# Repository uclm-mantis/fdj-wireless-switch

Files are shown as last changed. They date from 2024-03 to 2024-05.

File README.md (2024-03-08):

# FdJ Wireless Switch

Primera versión del conmutador inalámbrico para juguetes adaptados. Utiliza ESP Now! sin cifrado y sin filtrado de fuente.

## Configuración del emisor

En `emisor/main/main.cpp` editar la definición de pulsadores. El campo `.id` se utiliza para ligarlo a la salida con el mismo valor en el receptor.

```c
pulsador pulsadores[] = {
    {  .pin = 44, .id = 1 },
    {  .pin = 7,  .id = 2 },
    {  .pin = 8,  .id = 3 },
    {  .pin = 9,  .id = 4 },
};
```

En el mismo archivo, justo a continuación, editar la definición de `peer`. Solo debería editarse la MAC en `.peer_addr` y el canal WiFi en `.channel`.

```c
esp_now_peer_info_t peer = {
    .peer_addr = { 0x40, 0x4C, 0xCA, 0xF9, 0xE6, 0x34 },
    .channel = 0,
    .encrypt = false
};
```

## Configuración del receptor

En `receptor/main/main.cpp` editar la definición de las salidas. El campo `.id` debe coincidir con el correspondiente emisor. El campo `.pinModoPulsador` es una entrada digital para configurar modo pulsador (*press* activa, *release* desactiva) o modo conmutador (*press* conmuta el estado).

```c
salida salidas[] = {
    { .id = 1, .pin = 6,   .pinModoPulsador = 0 },
    { .id = 2, .pin = 7,   .pinModoPulsador = 1 },
    { .id = 3, .pin = 8,   .pinModoPulsador = 3 },
    { .id = 4, .pin = 10,  .pinModoPulsador = 4 },
};
```

# TODO

- Mecanismo para configurar peer.
- Deep sleep al menos en emisor.

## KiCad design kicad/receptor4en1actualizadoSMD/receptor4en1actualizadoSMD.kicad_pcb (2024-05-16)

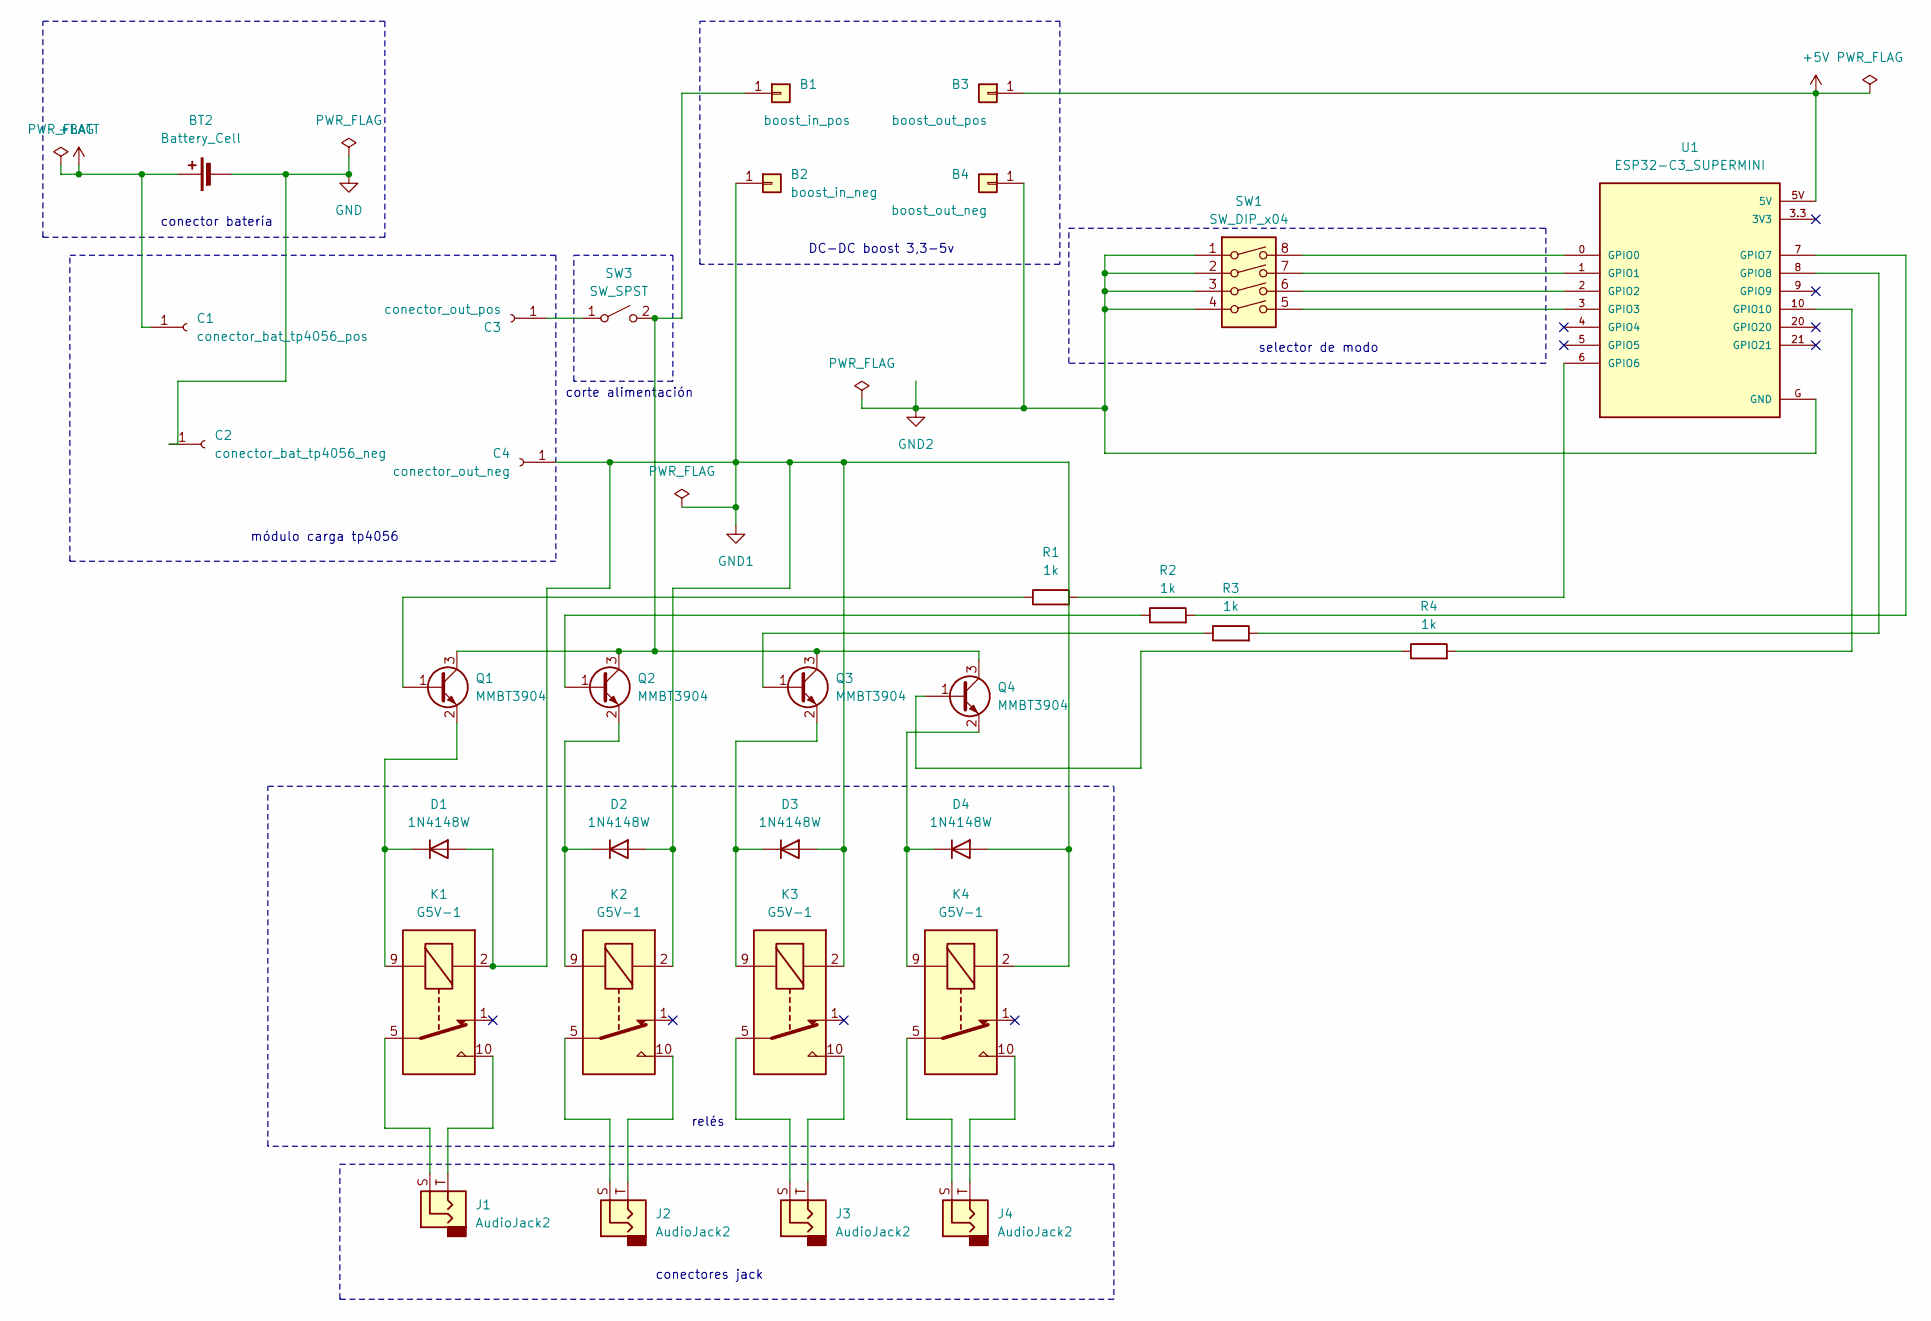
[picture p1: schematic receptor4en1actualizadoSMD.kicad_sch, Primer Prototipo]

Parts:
B1: boost_in_pos; PinHeader_1x01_P2.54mm_Vertical
B2: boost_in_neg; PinHeader_1x01_P2.54mm_Vertical
B3: boost_out_pos; PinHeader_1x01_P2.54mm_Vertical
B4: boost_out_neg; PinHeader_1x01_P2.54mm_Vertical
BT2: Battery_Cell; JST_PH_S2B-PH-K_1x02_P2.00mm_Horizontal
C1: conector_bat_tp4056_pos; PinHeader_1x01_P2.54mm_Vertical
C2: conector_bat_tp4056_neg; PinHeader_1x01_P2.54mm_Vertical
C3: conector_out_pos; PinHeader_1x01_P2.54mm_Vertical
C4: conector_out_neg; PinHeader_1x01_P2.54mm_Vertical
D1, D2, D3, D4: 1N4148W; D_SOD-123
J1, J2, J3, J4: AudioJack2; Jack_3.5mm_CUI_SJ1-3523N_Horizontal
K1, K2, K3, K4: G5V-1; Relay_SPDT_Omron_G5V-1
Q1, Q2, Q3, Q4: MMBT3904; SOT-23
R1, R2, R3, R4: 1k; R_0805_2012Metric_Pad1.20x1.40mm_HandSolder
SW1: SW_DIP_x04; DIP-8_W7.62mm_Socket
SW3: SW_SPST; JST_EH_S2B-EH_1x02_P2.50mm_Horizontal
U1: ESP32-C3_SUPERMINI; MODULE_ESP32-C3_SUPERMINI

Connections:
+5V: B3.1, U1.5V
+BATT: BT2.1 (+), C1.1
GND: BT2.2 (-), C2.1
GND1: B2.1, C4.1, D1.2 (A), D2.2 (A), D3.2 (A), D4.2 (A), K1.2, K2.2, K3.2, K4.2
GND2: B4.1, SW1.1, SW1.2, SW1.3, SW1.4, U1.G (GND)
unnamed: B1.1, Q1.3 (C), Q2.3 (C), Q3.3 (C), Q4.3 (C), SW3.2 (B)
unnamed: C3.1, SW3.1 (A)
unnamed: D1.1 (K), K1.9, Q1.2 (E)
unnamed: D2.1 (K), K2.9, Q2.2 (E)
unnamed: D3.1 (K), K3.9, Q3.2 (E)
unnamed: D4.1 (K), K4.9, Q4.2 (E)
unnamed: J1.S, K1.5, K1.6
unnamed: J1.T, K1.10
unnamed: J2.S, K2.5, K2.6
unnamed: J2.T, K2.10
unnamed: J3.S, K3.5, K3.6
unnamed: J3.T, K3.10
unnamed: J4.S, K4.5, K4.6
unnamed: J4.T, K4.10
unnamed: Q1.1 (B), R1.1
unnamed: Q2.1 (B), R2.1
unnamed: Q3.1 (B), R3.1
unnamed: Q4.1 (B), R4.1
unnamed: SW1.8, U1.0 (GPIO0)
unnamed: SW1.7, U1.1 (GPIO1)
unnamed: SW1.6, U1.2 (GPIO2)
unnamed: SW1.5, U1.3 (GPIO3)
unnamed: R1.2, U1.6 (GPIO6)
unnamed: R2.2, U1.7 (GPIO7)
unnamed: R3.2, U1.8 (GPIO8)
unnamed: R4.2, U1.10 (GPIO10)

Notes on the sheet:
conectores jack
selector de modo
relés
DC-DC boost 3,3-5v
corte alimentación
conector batería
módulo carga tp4056

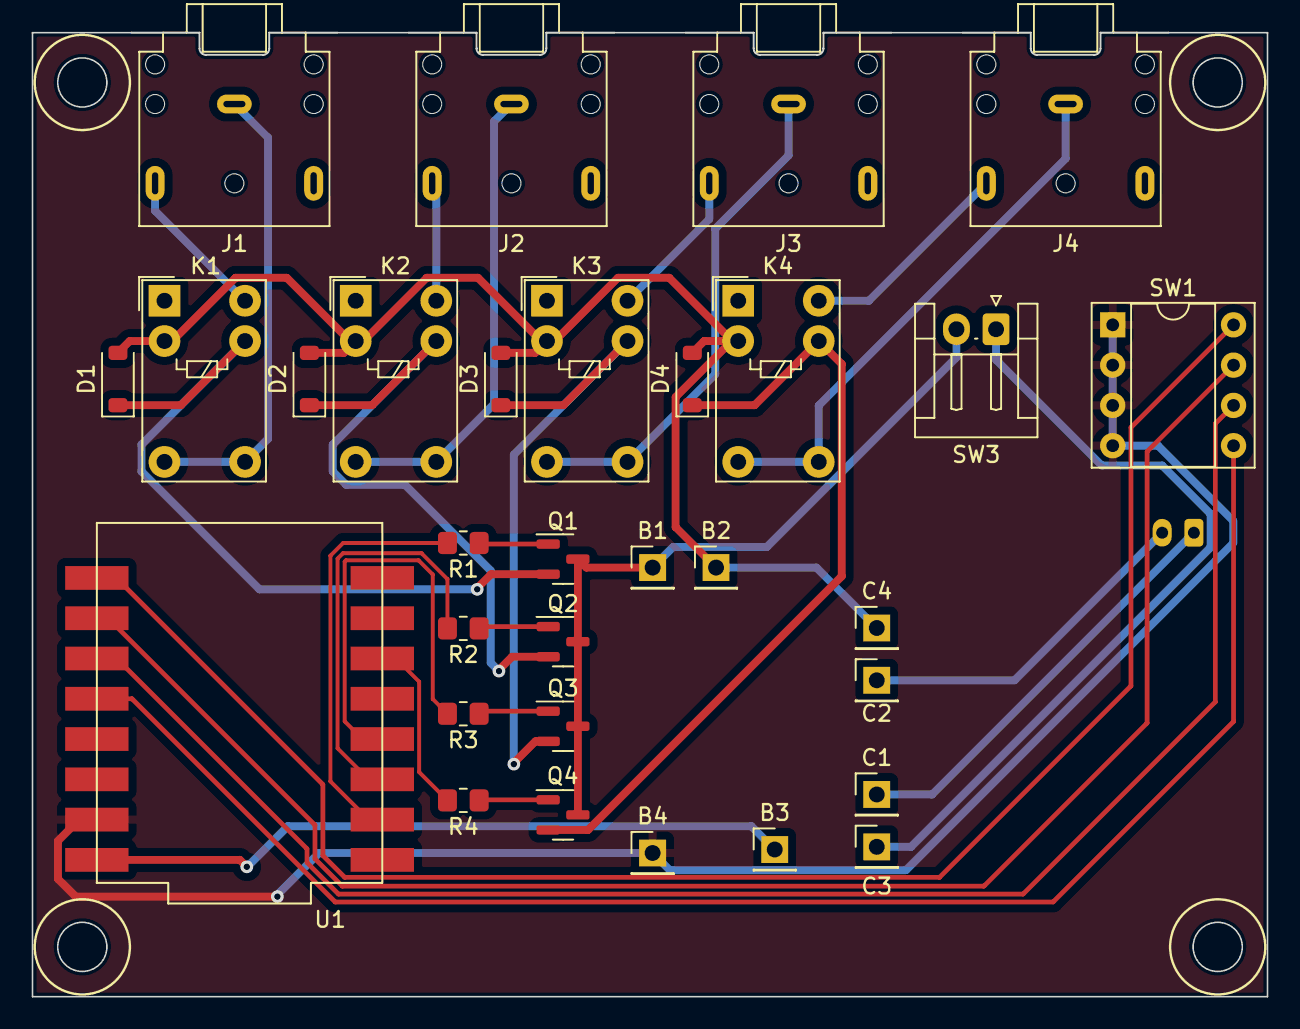
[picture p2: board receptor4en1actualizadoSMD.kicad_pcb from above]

Board: 2 copper layers, 77.9 x 60.8 mm, 32 parts (1 on the bottom side), 31 nets.

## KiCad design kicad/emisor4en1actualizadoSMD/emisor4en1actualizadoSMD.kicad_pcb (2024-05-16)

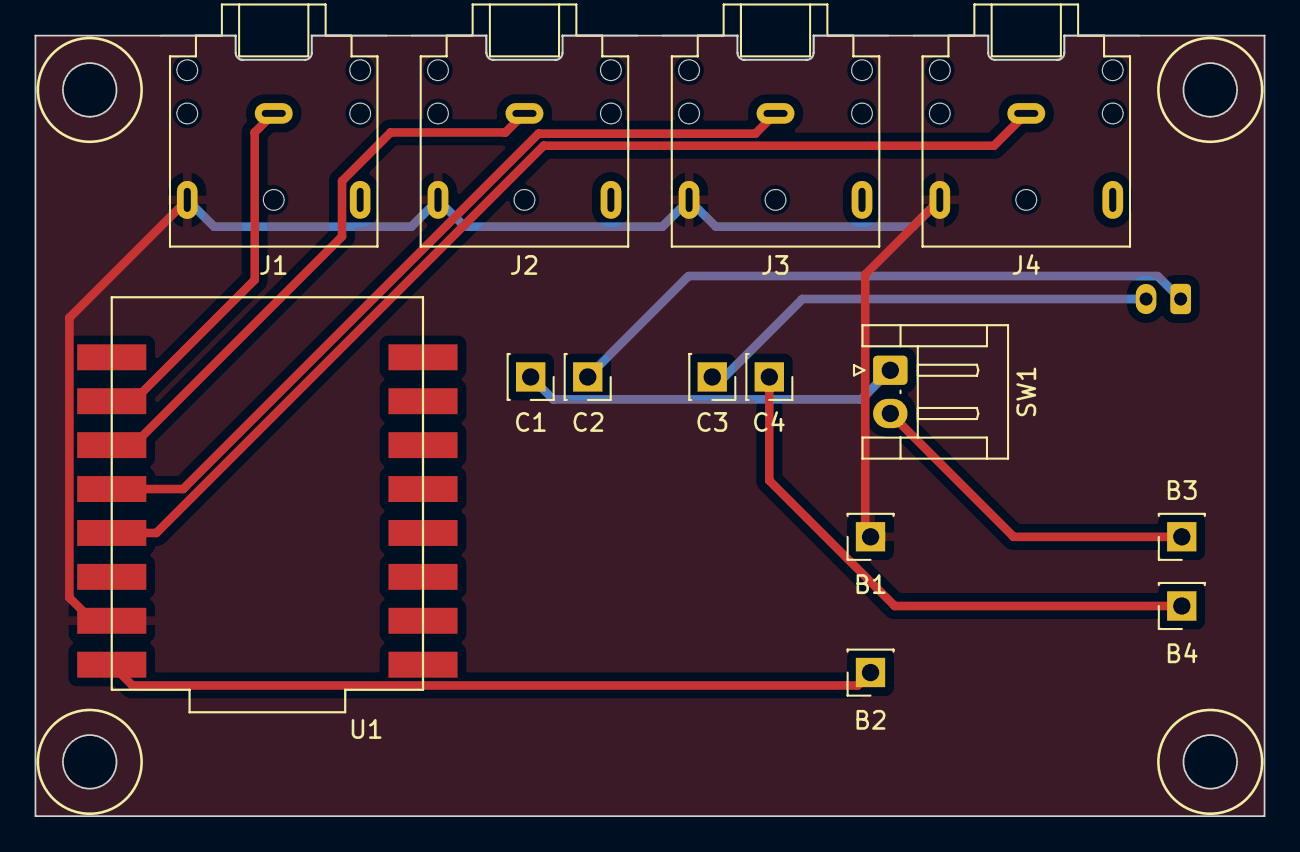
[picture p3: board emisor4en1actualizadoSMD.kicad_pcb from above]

Board: 2 copper layers, 71.1 x 45.1 mm, 15 parts (1 on the bottom side), 11 nets.

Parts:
B1, B2, B3, B4: Conn_01x01; PinSocket_1x01_P2.54mm_Vertical
BT1: Battery_Cell; JST_PH_S2B-PH-K_1x02_P2.00mm_Horizontal
C1: con_out_pos; PinSocket_1x01_P2.54mm_Vertical
C2: con_bat_tp4056_pos; PinSocket_1x01_P2.54mm_Vertical
C3: con_bat_tp4056_neg; PinSocket_1x01_P2.54mm_Vertical
C4: con_bat_neg; PinSocket_1x01_P2.54mm_Vertical
J1, J2, J3, J4: AudioJack2; Jack_3.5mm_CUI_SJ1-3523N_Horizontal
SW1: SW_SPST; JST_EH_S2B-EH_1x02_P2.50mm_Horizontal
U1: ESP32-C3_SUPERMINI; MODULE_ESP32-C3_SUPERMINI

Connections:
+5V: B2.1, U1.5V
+BATT: BT1.1 (+), C2.1
GND: BT1.2 (-), C3.1
GND1: B4.1, C4.1
GND2: B1.1, J1.T, J2.T, J3.T, J4.T, U1.G (GND)
unnamed: C1.1, SW1.1 (A)
unnamed: B3.1, SW1.2 (B)
unnamed: J1.S, U1.1 (GPIO1)
unnamed: J2.S, U1.2 (GPIO2)
unnamed: J3.S, U1.3 (GPIO3)
unnamed: J4.S, U1.4 (GPIO4)

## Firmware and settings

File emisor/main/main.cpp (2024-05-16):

#include <freertos/FreeRTOS.h>
#include <nvs_flash.h>
#include <esp_event.h>
#include <esp_netif.h>
#include <esp_wifi.h>
#include <esp_now.h>
#include <esp_log.h>
#include <driver/gpio.h>

#if CONFIG_ESPNOW_WIFI_MODE_STATION
#define ESPNOW_WIFI_MODE WIFI_MODE_STA
#define ESPNOW_WIFI_IF   WIFI_IF_STA
#else
#define ESPNOW_WIFI_MODE WIFI_MODE_AP
#define ESPNOW_WIFI_IF   WIFI_IF_AP
#endif

const char* TAG = "emisor";

typedef struct pulsador_ pulsador;
struct pulsador_ {
    const gpio_num_t pin;
    const uint8_t id;
    volatile bool presionado;
    volatile bool liberado;
    int lastV;
    TickType_t lastT;
};

pulsador pulsadores[] = {
    {  .pin = GPIO_NUM_1, .id = 1 },
    {  .pin = GPIO_NUM_2, .id = 2 },
    {  .pin = GPIO_NUM_3, .id = 3 },
    {  .pin = GPIO_NUM_4, .id = 4 },
};

const uint8_t N_PULSADORES = sizeof(pulsadores)/sizeof(pulsadores[0]);

// TODO: peer_addr should not be hardcoded
esp_now_peer_info_t peer = {
    .peer_addr = {  0xC0, 0x4E, 0x30, 0x82, 0x67, 0x6C },
    .channel = CONFIG_ESPNOW_CHANNEL,
    .ifidx = ESPNOW_WIFI_IF,
    .encrypt = false
};

typedef struct message_ {
  uint8_t id;
  bool presionado;
} message;

void register_button_event(pulsador* button) {
    int v = gpio_get_level(button->pin);
    if (v != button->lastV) { 
        button->presionado = (v == 0);
        button->liberado = (v != 0);
        button->lastV = v;
    }
}

void isr(void* param) {
    pulsador* button = (pulsador*) param;
    TickType_t current = xTaskGetTickCountFromISR();
    if (current - button->lastT > 50 / portTICK_PERIOD_MS) { // debouncing
        register_button_event(button);
        button->lastT = current;
    }
}

static void check_button_event(pulsador* button) {
    if (!button->presionado && !button->liberado) return;

    ESP_LOGI(TAG, "event %d %s", button->id, button->presionado?"PRESSED":"RELEASED");
    message msg = { button->id, button->presionado };
    ESP_ERROR_CHECK_WITHOUT_ABORT(esp_now_send(peer.peer_addr, (uint8_t *)&msg, sizeof(msg)));
    button->presionado = false; button->liberado = false;
}

static void entradas_init() {

    for (pulsador* p = pulsadores; p < pulsadores + N_PULSADORES; ++p) {
        gpio_reset_pin(p->pin);
        gpio_set_direction(p->pin, GPIO_MODE_INPUT);
        gpio_pullup_en(p->pin);
        gpio_set_intr_type(p->pin, GPIO_INTR_ANYEDGE);
        p->lastV = !gpio_get_level(p->pin);
        p->lastT = xTaskGetTickCount();
        gpio_isr_handler_add(p->pin, isr, p);
    }
}

static void wifi_init()
{
    // initialize NVS
    esp_err_t ret = nvs_flash_init();
    if (ret == ESP_ERR_NVS_NO_FREE_PAGES || ret == ESP_ERR_NVS_NEW_VERSION_FOUND) {
        ESP_ERROR_CHECK(nvs_flash_erase());
        ret = nvs_flash_init();
    }
    ESP_ERROR_CHECK(ret);
    ESP_ERROR_CHECK(esp_netif_init());
    ESP_ERROR_CHECK(esp_event_loop_create_default());
    wifi_init_config_t cfg = WIFI_INIT_CONFIG_DEFAULT();
    ESP_ERROR_CHECK(esp_wifi_init(&cfg));
    ESP_ERROR_CHECK(esp_wifi_set_storage(WIFI_STORAGE_RAM));
    ESP_ERROR_CHECK(esp_wifi_set_mode(ESPNOW_WIFI_MODE));
    ESP_ERROR_CHECK(esp_wifi_start());
    ESP_ERROR_CHECK(esp_wifi_set_channel(CONFIG_ESPNOW_CHANNEL, WIFI_SECOND_CHAN_NONE));

#if CONFIG_ESPNOW_ENABLE_LONG_RANGE
    ESP_ERROR_CHECK( esp_wifi_set_protocol(ESPNOW_WIFI_IF, WIFI_PROTOCOL_11B|WIFI_PROTOCOL_11G|WIFI_PROTOCOL_11N|WIFI_PROTOCOL_LR) );
#endif
}

static void espnow_send_cb(const uint8_t *mac, esp_now_send_status_t status)
{
    if (status != ESP_NOW_SEND_SUCCESS)
        ESP_LOGI(TAG, "Delivery failed %02x:%02x:%02x:%02x:%02x:%02x", mac[0],mac[1],mac[2],mac[3],mac[4],mac[5]);
}

static void espnow_init()
{
    ESP_ERROR_CHECK(esp_now_init());
    ESP_ERROR_CHECK(esp_now_register_send_cb(espnow_send_cb));
#if CONFIG_ESPNOW_ENABLE_POWER_SAVE
    ESP_ERROR_CHECK(esp_now_set_wake_window(CONFIG_ESPNOW_WAKE_WINDOW));
    ESP_ERROR_CHECK(esp_wifi_connectionless_module_set_wake_interval(CONFIG_ESPNOW_WAKE_INTERVAL));
#endif
    /* Set primary master key. */
    ESP_ERROR_CHECK(esp_now_set_pmk((uint8_t *)CONFIG_ESPNOW_PMK));
    ESP_ERROR_CHECK(esp_now_add_peer(&peer));
}

extern "C" void app_main(void)
{
    entradas_init();
    wifi_init();
    espnow_init();
    TickType_t last = xTaskGetTickCount();
    for(;;) {
        for (pulsador* p = pulsadores; p < pulsadores + N_PULSADORES; ++p) {
            check_button_event(p);
        }
        xTaskDelayUntil(&last, 50/ portTICK_PERIOD_MS);
        for (pulsador* p = pulsadores; p < pulsadores + N_PULSADORES; ++p) {
            register_button_event(p);
        }
        // go to sleep
    }
}

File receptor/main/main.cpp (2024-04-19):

#include <freertos/FreeRTOS.h>
#include <nvs_flash.h>
#include <esp_event.h>
#include <esp_netif.h>
#include <esp_wifi.h>
#include <esp_now.h>
#include <esp_log.h>
#include <driver/gpio.h>

#if CONFIG_ESPNOW_WIFI_MODE_STATION
#define ESPNOW_WIFI_MODE WIFI_MODE_STA
#define ESPNOW_WIFI_IF   ESP_IF_WIFI_STA
#else
#define ESPNOW_WIFI_MODE WIFI_MODE_AP
#define ESPNOW_WIFI_IF   ESP_IF_WIFI_AP
#endif

static const char *TAG = "receptor";

typedef struct salida_ salida;
struct salida_
{
    const uint8_t id;
    const gpio_num_t pin;
    const gpio_num_t pinModoPulsador;
    unsigned v;
};

salida salidas[] = {
    { .id = 1, .pin = GPIO_NUM_6,  .pinModoPulsador = GPIO_NUM_3, .v = 0 },
    { .id = 2, .pin = GPIO_NUM_7,  .pinModoPulsador = GPIO_NUM_2, .v = 0 },
    { .id = 3, .pin = GPIO_NUM_8,  .pinModoPulsador = GPIO_NUM_1, .v = 0 },
    { .id = 4, .pin = GPIO_NUM_10,  .pinModoPulsador = GPIO_NUM_0, .v = 0 },
};

const uint8_t N_SALIDAS = sizeof(salidas) / sizeof(salidas[0]);


static void salidas_init()
{
    for (salida* s = salidas; s < salidas + N_SALIDAS; ++s) {
        gpio_reset_pin(s->pin);
        gpio_set_direction(s->pin, GPIO_MODE_OUTPUT);
        
        gpio_reset_pin(s->pinModoPulsador);
        gpio_set_direction(s->pinModoPulsador, GPIO_MODE_INPUT);
        gpio_pullup_en(s->pinModoPulsador);
        gpio_set_level(s->pin, (s->v = 0));
    }
}

static void wifi_init()
{
    // initialize NVS
    esp_err_t ret = nvs_flash_init();
    if (ret == ESP_ERR_NVS_NO_FREE_PAGES || ret == ESP_ERR_NVS_NEW_VERSION_FOUND) {
        ESP_ERROR_CHECK(nvs_flash_erase());
        ret = nvs_flash_init();
    }
    ESP_ERROR_CHECK(ret);
    ESP_ERROR_CHECK(esp_netif_init());
    ESP_ERROR_CHECK(esp_event_loop_create_default());
    wifi_init_config_t cfg = WIFI_INIT_CONFIG_DEFAULT();
    ESP_ERROR_CHECK(esp_wifi_init(&cfg));
    ESP_ERROR_CHECK(esp_wifi_set_storage(WIFI_STORAGE_RAM));
    ESP_ERROR_CHECK(esp_wifi_set_mode(ESPNOW_WIFI_MODE));
    ESP_ERROR_CHECK(esp_wifi_start());
    ESP_ERROR_CHECK(esp_wifi_set_channel(CONFIG_ESPNOW_CHANNEL, WIFI_SECOND_CHAN_NONE));

#if CONFIG_ESPNOW_ENABLE_LONG_RANGE
    ESP_ERROR_CHECK( esp_wifi_set_protocol(ESPNOW_WIFI_IF, WIFI_PROTOCOL_11B|WIFI_PROTOCOL_11G|WIFI_PROTOCOL_11N|WIFI_PROTOCOL_LR) );
#endif
}

typedef struct message_ {
  uint8_t id;
  bool presionado;
} message;

static void espnow_receiver_cb(const esp_now_recv_info_t * info, const uint8_t *data, int data_len)
{
    message* msg = (message*)data;

    // TODO: si recibe broadcast añade a la lista de peers (ver ejemplo de ESP-IDF)
    for (salida* s = salidas; s < salidas + N_SALIDAS; ++s) {
        if (msg->id == s->id) {
            if (gpio_get_level(s->pinModoPulsador)) gpio_set_level(s->pin, (s->v = msg->presionado));
            else if (msg->presionado) gpio_set_level(s->pin, (s->v = !s->v));
            ESP_LOGI(TAG, "Hit %d = %d (%s)", msg->id, s->v, msg->presionado?"PRESS":"RELEASE");
            break;
        }
    }
}

static void espnow_init()
{
    ESP_ERROR_CHECK(esp_now_init());
    ESP_ERROR_CHECK(esp_now_register_recv_cb(espnow_receiver_cb));
#if CONFIG_ESPNOW_ENABLE_POWER_SAVE
    ESP_ERROR_CHECK(esp_now_set_wake_window(CONFIG_ESPNOW_WAKE_WINDOW));
    ESP_ERROR_CHECK(esp_wifi_connectionless_module_set_wake_interval(CONFIG_ESPNOW_WAKE_INTERVAL));
#endif
    ESP_ERROR_CHECK(esp_now_set_pmk((uint8_t *)CONFIG_ESPNOW_PMK));
}

extern "C" void app_main(void)
{
    salidas_init();
    wifi_init();
    espnow_init();
}

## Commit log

2024-03-07 First version wireless switch
    Caveats: no encryption, no channel selection, no peer selection.
2024-03-07 Untested version of non-arduino version
2024-03-07 Fixed emisor, still missing deep sleep
    [main.cpp]
2024-03-07 fixed small bugs, tested in esp32c3
    [main.cpp]
2024-03-07 Tested no-arduino branch, committing to master
2024-03-07 Squashed commit of the following:
    commit 17d71aa247266536494794c1b42f3f88f843305c
    Author: Francisco Moya <francisco.moya@uclm.es>
    Date: Thu Mar 7 20:20:40 2024 +0100
    Tested no-arduino branch, committing to master
    commit 7db730e6e573933042eab5c73b25572907f4b427
    Author: Francisco Moya <francisco.moya@uclm.es>
    Date: Thu Mar 7 12:44:11 2024 +0100
    Fixed emisor, still missing deep sleep
    commit 4ce90d46c1385b5ce9e25c331811f315dbb092ad
    Author: Francisco Moya <francisco.moya@uclm.es>
    Date: Thu Mar 7 10:53:21 2024 +0100
    Untested version of non-arduino version
    [main.cpp]
